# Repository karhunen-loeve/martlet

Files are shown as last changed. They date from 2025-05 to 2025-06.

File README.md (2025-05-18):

# martlet
Ergogen designed minimalist keyboard 

The Martlet is intended to be a minimalist keyboard that I plan to use primarily for traveling. I've previously used a low-profile Corne keyboard (42 keys). For this reason, the Martlet is intended to be based on the Corne design. The main difference is that it won't be a split design, and the keyboard will be wireless. Essentially, both halves of the Corne will be glued together. I might adjust the position of the little finger keys a bit to suit my anatomy.

# Key Features

- Wireless
- Similar to corne layout
- 42 Keys (Maybe only 40 Keys)
- More staggered pinky colmn
- No RGB lights
- No Frills

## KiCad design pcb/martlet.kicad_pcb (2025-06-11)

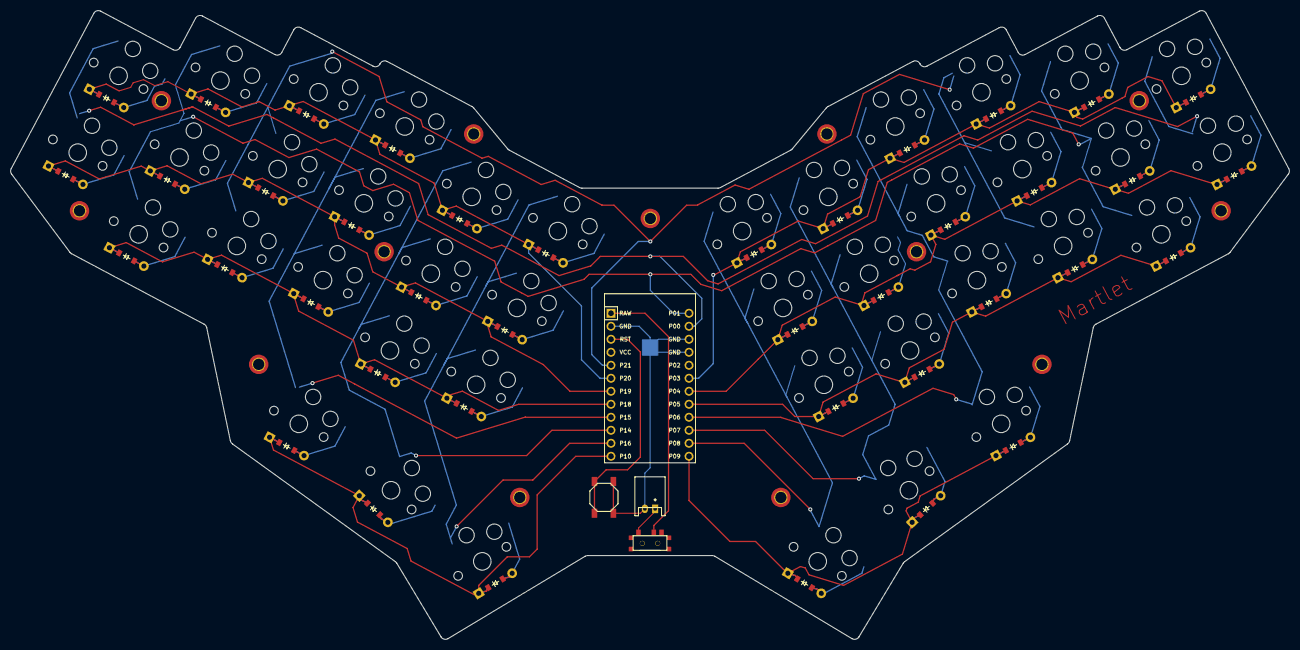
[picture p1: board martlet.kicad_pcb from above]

Board: 2 copper layers, 249.8 x 122.8 mm, 84 parts (0 on the bottom side), 61 nets.

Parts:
B1: SW_TACT_ALPS_SKQGABE010
D1, D2, D3, D4, D5, D6, D7, D8, D9, D10, D11, D12, D13, D14, D15, D16, D17, D18, D19, D20, D21, D22, D23, D24, D25, D26, D27, D28, D29, D30, D31, D32, D33, D34, D35, D36, D37, D38, D39, D40: ComboDiode
JST1: JST_PH_S2B-PH-K_02x2.00mm_Angled
MCU1: ProMicro
S1, S2, S3, S4, S5, S6, S7, S8, S9, S10, S11, S12, S13, S14, S15, S16, S17, S18, S19, S20, S21, S22, S23, S24, S25, S26, S27, S28, S29, S30, S31, S32, S33, S34, S35, S36, S37, S38, S39, S40: PG1350
T1: SPDT_C128955

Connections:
GND: B1.1, JST1.2, MCU1.2, MCU1.15, MCU1.16
P0: MCU1.14, S1.1, S2.1, S21.1, S22.1
P1: MCU1.13, S3.1, S4.1, S5.1, S23.1, S24.1, S25.1
P3: D22.1, D25.1, D28.1, D31.1, D34.1, D37.1, MCU1.18
P4: D21.1, D24.1, D27.1, D30.1, D33.1, D36.1, MCU1.19
P5: D23.1, D26.1, D29.1, D32.1, D35.1, MCU1.20
P6: MCU1.21, S29.1, S30.1, S31.1, S38.1
P7: MCU1.22, S32.1, S33.1, S34.1, S39.1
P8: MCU1.23, S35.1, S36.1, S37.1, S40.1
P9: D38.1, D39.1, D40.1, MCU1.24
P10: D18.1, D19.1, D20.1, MCU1.12
P14: MCU1.10, S12.1, S13.1, S14.1, S19.1
P15: MCU1.9, S9.1, S10.1, S11.1, S18.1
P16: MCU1.11, S15.1, S16.1, S17.1, S20.1
P18: D3.1, D6.1, D9.1, D12.1, D15.1, MCU1.8
P19: D1.1, D4.1, D7.1, D10.1, D13.1, D16.1, MCU1.7
P20: D2.1, D5.1, D8.1, D11.1, D14.1, D17.1, MCU1.6
P21: MCU1.5, S6.1, S7.1, S8.1, S26.1, S27.1, S28.1
RAW: MCU1.1, T1.2
RST: B1.2, MCU1.3
index_bottom: D12.2, S12.2
index_home: D13.2, S13.2
index_top: D14.2, S14.2
inner_bottom: D15.2, S15.2
inner_home: D16.2, S16.2
inner_top: D17.2, S17.2
left_cluster: D18.2, S18.2
middle_bottom: D9.2, S9.2
middle_cluster: D19.2, S19.2
middle_home: D10.2, S10.2
middle_top: D11.2, S11.2
mirror_index_bottom: D32.2, S32.2
mirror_index_home: D33.2, S33.2
mirror_index_top: D34.2, S34.2
mirror_inner_bottom: D35.2, S35.2
mirror_inner_home: D36.2, S36.2
mirror_inner_top: D37.2, S37.2
mirror_left_cluster: D38.2, S38.2
mirror_middle_bottom: D29.2, S29.2
mirror_middle_cluster: D39.2, S39.2
mirror_middle_home: D30.2, S30.2
mirror_middle_top: D31.2, S31.2
mirror_outer_home: D21.2, S21.2
mirror_outer_top: D22.2, S22.2
mirror_pinky_bottom: D23.2, S23.2
mirror_pinky_home: D24.2, S24.2
mirror_pinky_top: D25.2, S25.2
mirror_right_cluster: D40.2, S40.2
mirror_ring_bottom: D26.2, S26.2
mirror_ring_home: D27.2, S27.2
mirror_ring_top: D28.2, S28.2
outer_home: D1.2, S1.2
outer_top: D2.2, S2.2
pinky_bottom: D3.2, S3.2
pinky_home: D4.2, S4.2
pinky_top: D5.2, S5.2
pos: JST1.1, T1.1
right_cluster: D20.2, S20.2
ring_bottom: D6.2, S6.2
ring_home: D7.2, S7.2
ring_top: D8.2, S8.2

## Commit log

2025-05-18 finish board outline (for now)
2025-05-20 add row and column net information for the pcb layout
2025-05-20 fix row_net pin names
2025-05-23 add slider, reset button and battery connector to pcb
2025-05-24 change column and row net in order to optimize kicad-lines
2025-05-24 fix row 6 pin connection
2025-05-27 fix row 2 pin connection
2025-06-11 add kicad file
    The file contains:
    - the actual routing
    - vias
    - mounting holes (M2)
    - `Martlet` title
    [martlet.kicad_pcb]
2025-06-11 adjust "Martlet" title on the front of the pcb/martlet
    Remark: This is the design I ordered the pcb
    [martlet.kicad_pcb]
